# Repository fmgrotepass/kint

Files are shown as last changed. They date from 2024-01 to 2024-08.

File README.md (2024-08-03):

# Project moved to [Pillz Mod](https://github.com/dcpedit/pillzmod)
<p align="center">
  
</p>

This project has been replaced by Pillz Mod: https://github.com/dcpedit/pillzmod

# KinT Blackpill Edition

kinesis-3

This is a fork of Michael Stapelberg's [KinT project](https://github.com/kinx-project/kint) with the following modifications:

* Replaced Teensy with STM32F411 Blackpill controller (`blackpill` directory)
* Reduced PCB size to 100 x 86 mm
* Use Vial firmware.  Source code is in my [fork of Vial](https://github.com/dcpedit/vial-qmk-dev/tree/vial/keyboards/dcpedit/kint_bp)

## Files for JLCPCB
Located in the directory `/blackpill/production`

## Parts for Build
| Component | Qty | Notes |
| --- | --- | ----- |
| SMD LEDs | 4 | Can be any color [Link](https://octopart.com/apt3216qbc%2Fd-kingbright-5355642?r=sp)
| SMD 10k resistors | 4 | [Link](https://octopart.com/crcw120610k0fkeac-vishay-20811529)
| Molex 13 pin connectors| 4-6 | Needed if you don't want to desolder old ones [Link](https://octopart.com/39-53-2135-molex-7670149?r=sp)
| STM32F411 Blackpill | 1 | AliExpress [Link](https://www.aliexpress.us/item/3256801269871873.html)
| Panel mount USB-C | 1 | Amazon [Link](https://a.co/d/cRoqHqx)
| Socketed headers | | Only needed if you want to socket your Blackpill.

## Bluetooth + ZMK build
You can now use the Pillbug dev board along with ZMK firware to make this a wireless mod.  Basically, just swap out the Blackpill with a Pillbug and add a battery.

| Component | Qty | Notes |
| --- | --- | ----- |
| Pillbug | 1 | MechWild [Link](https://mechwild.com/product/pillbug/)
| 2000 mAh battery | 1 | Amazon [Link](https://a.co/d/hlTVT1p)

v2022-08-05 of the PCB requires you to bridge the 3.3v pins with a wire.  You can do this easily after soldering the controller in place and tacking a short wire with stripped ends to the existing solder joints on the same side as the LEDs/resistors.  The diagram below shows you which pins.

bridge

The current version in the repo does not require this.

If you're using a battery that's larger than 500 mAh, short JP1 on the back of the Pillbug to enable "Charge Boost" (changes charge rate from 100mA to 500mA)

## Firmware
### Vial
Source: https://github.com/dcpedit/vial-qmk-dev/tree/vial/keyboards/dcpedit/kint_bp
* `/firmware/dcpedit_kint_bp_vial.bin` - Default keymap (stock Kinesis)
* `/firmware/dcpedit_kint_bp_vial_6layers.bin` - Support for 6 layers

### ZMK
Source: https://github.com/dcpedit/zmk/tree/kinesispb/app/boards/shields/kinesispb
* `/firmware/zmk_default.uf2` - Default keymap (stock Kinesis)
* `/firmware/zmk_reset.uf2` - Resets PillBug board for BT connectivity issue on MacOS

### Flashing firmware under Linux
The file firmware/dcpedit_kint_bp_vial.bin (or other) can simply be flashed to the Blackpill using the dfu-util. The dfu-util tool requires root privileges if settings are not accessible by the user.

Connect Blackpill to your Linux PC via USB C cable and start unit in DFU mode by holding bootp button and pressing reset button. Wait a second and release the bootp button.

Check the DFU devices by running
```
dfu-util -l
```
The Blackpill device should be visible.

Write the firmware to the device with
```
dfu-util -d 0483:df11 -a 0 -s 0x08000000 -D [PATH TO kint]/firmware/dcpedit_kint_bp_vial.bin
```

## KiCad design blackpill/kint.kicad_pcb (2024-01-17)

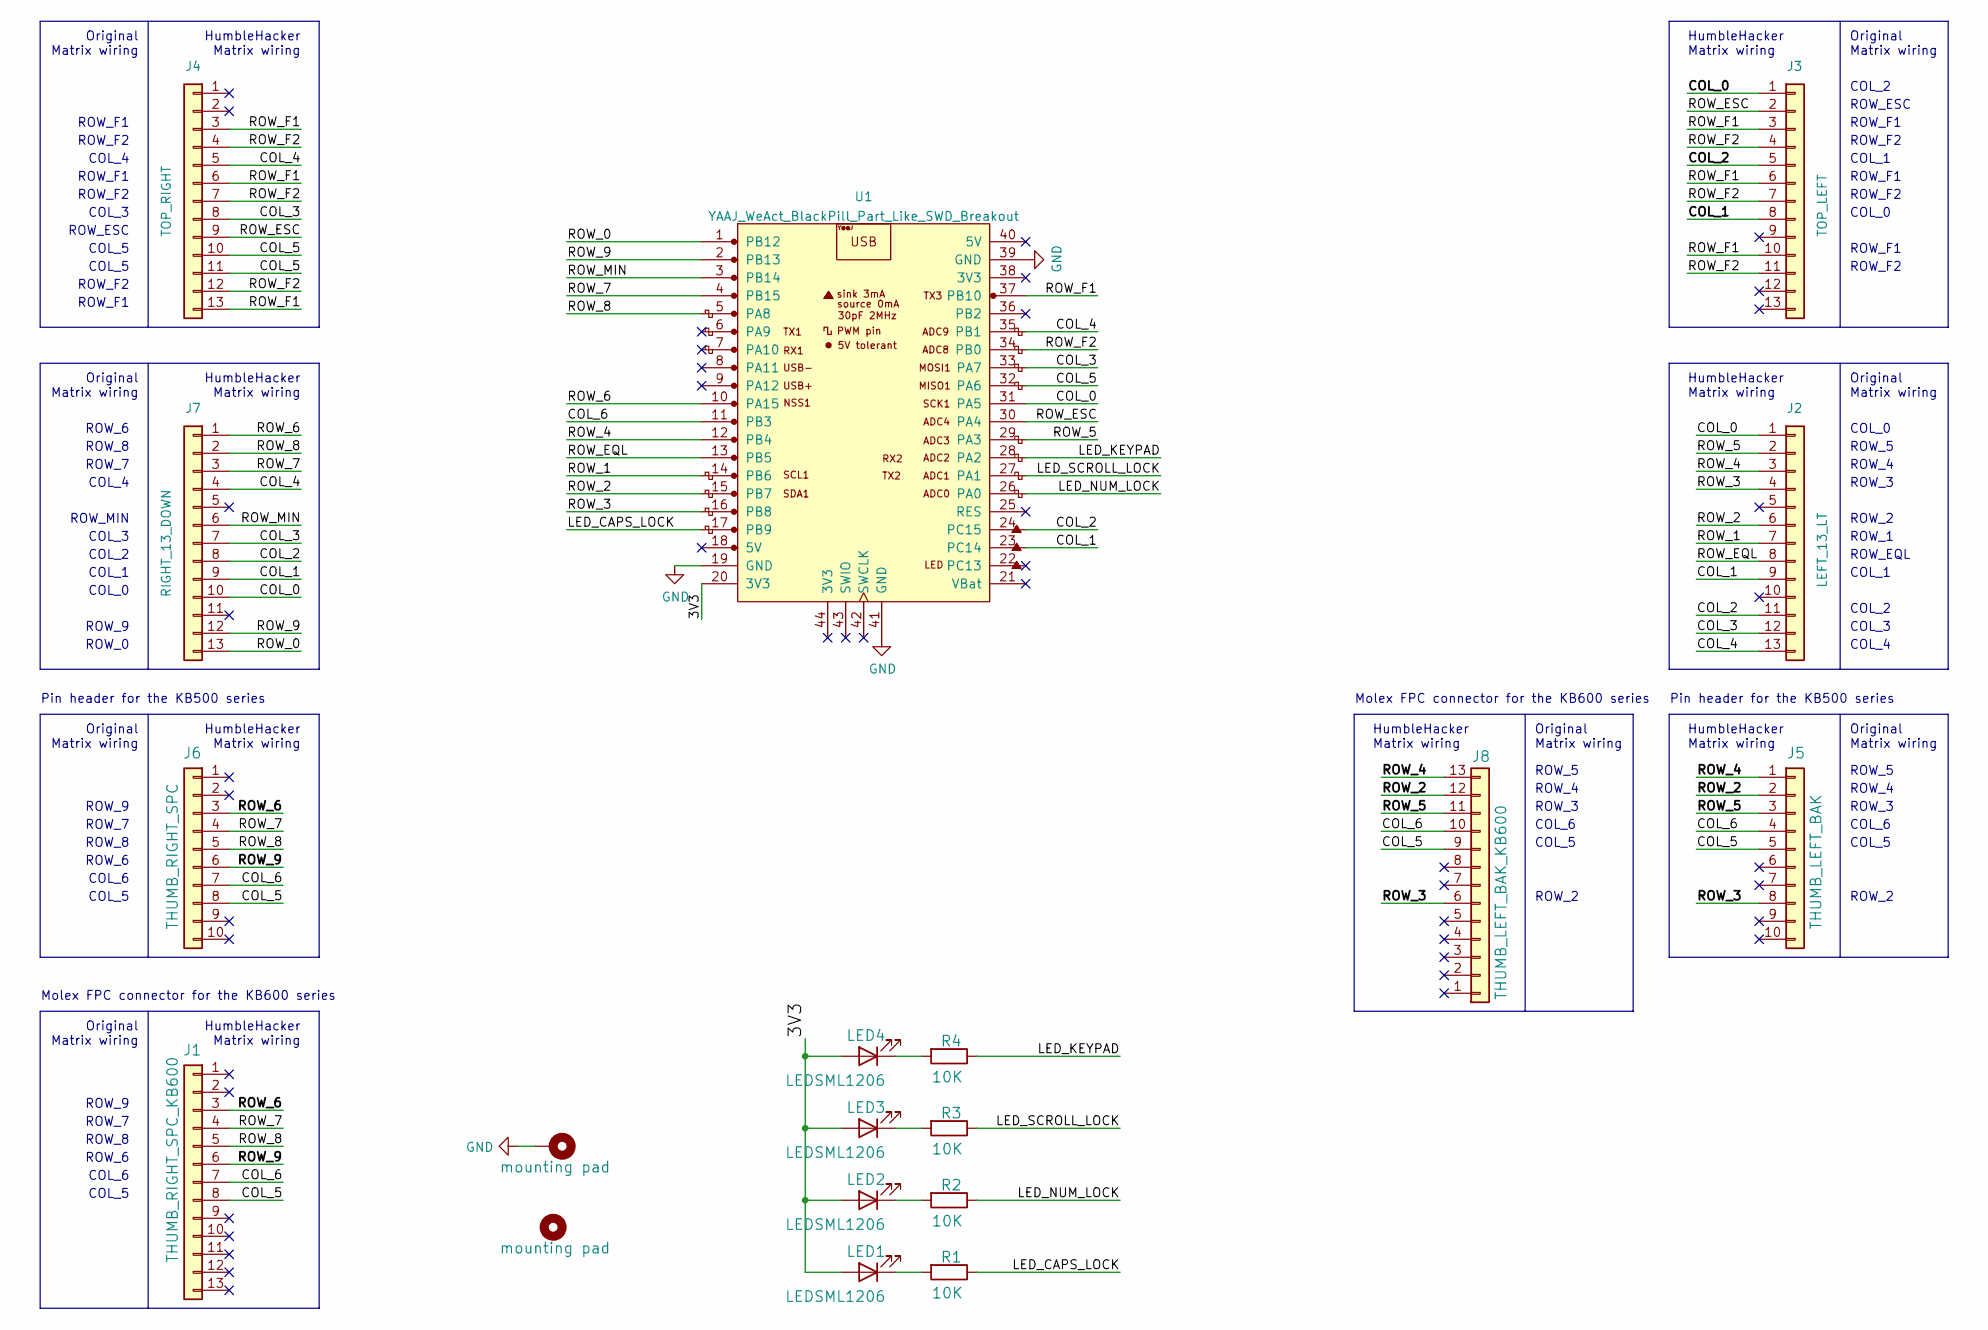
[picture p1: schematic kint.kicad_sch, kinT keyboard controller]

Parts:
H1: mounting pad; MountingHole_4.3mm_M4_Pad
H2: mounting pad; MountingHole_6mm
J1: THUMB_RIGHT_SPC_KB600; 39-53-2135; MPN 39-53-2135; digikeypn WM14526-ND
J2: LEFT_13_LT; 39-53-2135; MPN 39-53-2135; digikeypn WM14526-ND
J3: TOP_LEFT; 39-53-2135; MPN 39-53-2135; digikeypn WM14526-ND
J4: TOP_RIGHT; 39-53-2135; MPN 39-53-2135; digikeypn WM14526-ND
J5: THUMB_LEFT_BAK; PinHeader_1x10_P2.54mm_Vertical; MPN 39-53-2135; digikeypn WM14526-ND
J6: THUMB_RIGHT_SPC; PinHeader_1x10_P2.54mm_Vertical; MPN 39-53-2135; digikeypn WM14526-ND
J7: RIGHT_13_DOWN; 39-53-2135; MPN 39-53-2135; digikeypn WM14526-ND
J8: THUMB_LEFT_BAK_KB600; 39-53-2135; MPN 39-53-2135; digikeypn WM14526-ND
LED1, LED2, LED3, LED4: LEDSML1206; LED_1206_3216Metric_Pad1.42x1.75mm_HandSolder; MPN APT3216QBC/D; digikeypn 754-1439-1-ND
R1, R2, R3, R4: 10K; R_1206_3216Metric_Pad1.42x1.75mm_HandSolder; MPN CRCW120610K0FKEAC; digikeypn 541-3983-1-ND
U1: YAAJ_WeAct_BlackPill_Part_Like_SWD_Breakout; YAAJ_WeAct_BlackPill_SWD_2

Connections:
/3V3: LED1.2 (A), LED2.2 (A), LED3.2 (A), LED4.2 (A), U1.20 (3V3)
/COL_0: J2.1, J3.1, J7.10, U1.31 (PA5)
/COL_1: J2.9, J3.8, J7.9, U1.23 (PC14)
/COL_2: J2.11, J3.5, J7.8, U1.24 (PC15)
/COL_3: J2.12, J4.8, J7.7, U1.33 (PA7)
/COL_4: J2.13, J4.5, J7.4, U1.35 (PB1)
/COL_5: J1.8, J4.10, J4.11, J5.5, J6.8, J8.9, U1.32 (PA6)
/COL_6: J1.7, J5.4, J6.7, J8.10, U1.11 (PB3)
/LED_CAPS_LOCK: R1.1, U1.17 (PB9)
/LED_KEYPAD: R4.1, U1.28 (PA2)
/LED_NUM_LOCK: R2.1, U1.26 (PA0)
/LED_SCROLL_LOCK: R3.1, U1.27 (PA1)
/ROW_0: J7.13, U1.1 (PB12)
/ROW_1: J2.7, U1.14 (PB6)
/ROW_2: J2.6, J5.2, J8.12, U1.15 (PB7)
/ROW_3: J2.4, J5.8, J8.6, U1.16 (PB8)
/ROW_4: J2.3, J5.1, J8.13, U1.12 (PB4)
/ROW_5: J2.2, J5.3, J8.11, U1.29 (PA3)
/ROW_6: J1.3, J6.3, J7.1, U1.10 (PA15)
/ROW_7: J1.4, J6.4, J7.3, U1.4 (PB15)
/ROW_8: J1.5, J6.5, J7.2, U1.5 (PA8)
/ROW_9: J1.6, J6.6, J7.12, U1.2 (PB13)
/ROW_EQL: J2.8, U1.13 (PB5)
/ROW_ESC: J3.2, J4.9, U1.30 (PA4)
/ROW_F1: J3.3, J3.6, J3.10, J4.3, J4.6, J4.13, U1.37 (PB10)
/ROW_F2: J3.4, J3.7, J3.11, J4.4, J4.7, J4.12, U1.34 (PB0)
/ROW_MIN: J7.6, U1.3 (PB14)
GND: H1.1, U1.19 (GND), U1.39 (GND), U1.41 (GND)
unnamed: LED1.1 (K), R1.2
unnamed: LED2.1 (K), R2.2
unnamed: LED3.1 (K), R3.2
unnamed: LED4.1 (K), R4.2

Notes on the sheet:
COL_6
ROW_F2
ROW_6
Pin header for the KB500 series
Molex FPC connector for the KB600 series
ROW_7
COL_3
ROW_4
ROW_ESC
COL_0
ROW_3
ROW_2
ROW_1
Original Matrix wiring
ROW_5
ROW_MIN
ROW_F1
HumbleHacker Matrix wiring
ROW_EQL
ROW_9
COL_4
COL_5
COL_1
COL_2
ROW_8
ROW_0

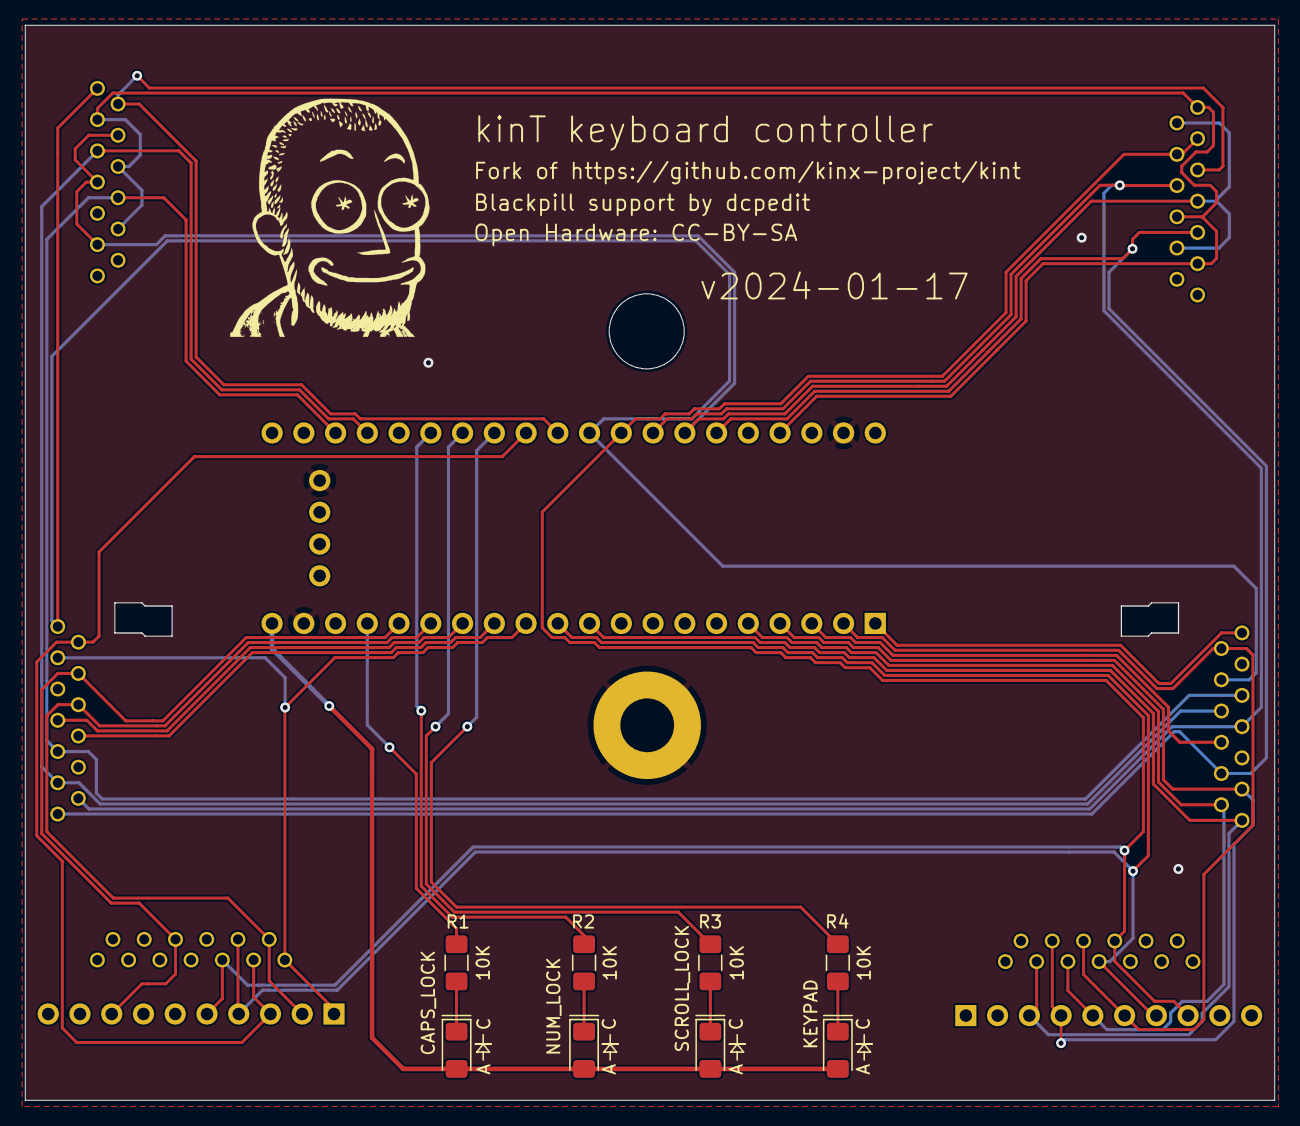
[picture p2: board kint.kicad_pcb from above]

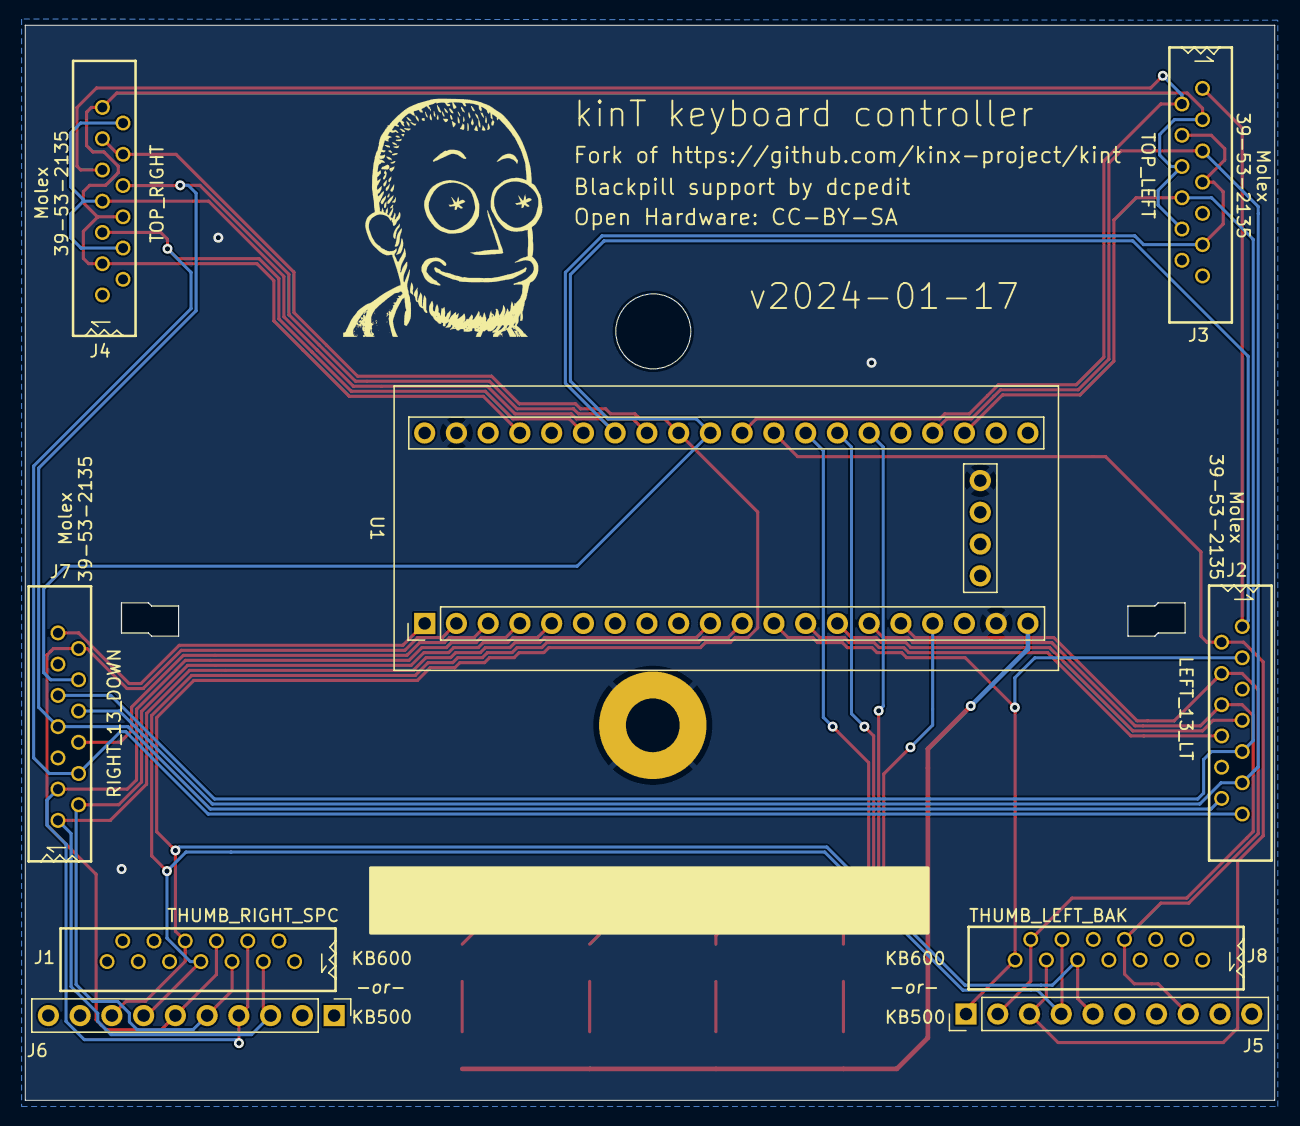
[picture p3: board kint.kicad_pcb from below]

Board: 2 copper layers, 99.9 x 86.0 mm, 19 parts (9 on the bottom side), 32 nets.

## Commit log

2022-08-19 Blackpill support
    [kint-B_Cu.gbl, kint-B_Mask.gbs, kint-B_Paste.gbp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]
2024-01-17 Update to remove the need to connect center pins
    [kint.kicad_pcb, kint.kicad_sch]
2024-01-17 Regenerate jlcpcb files
    [kint-B_Cu.gbl, kint-B_Mask.gbs, kint-B_Paste.gbp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]
2024-01-17 Update README.md with wire bridge

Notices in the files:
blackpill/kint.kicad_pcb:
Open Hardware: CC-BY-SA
